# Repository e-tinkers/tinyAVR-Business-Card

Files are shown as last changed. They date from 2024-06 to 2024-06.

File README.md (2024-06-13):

## tinyAVR Business Card

This is my entry for Hackaday 2024 Business Card Challenge Contest.

A business card with contact info and QR Code, plus a charlieplexed realtime clock powered by a CR2016 coin cell with extremely low battery power consumption, it is also a complete ATtiny3227 development board with all the pins break-out.

"PCB name card side"
"PCB component side"

### Feature Highlights

- Business with contact information and QRCode for website
- Credit card size of 85.5x54mm
- 3.2mm thickness including 1mm PCB
- It is a clock/watch with 12 Charlieplexing LEDs
- It is also a ATtiny3227 development board with all the pins (22-GPIO pins) break-out.
- Programmable with [megaTinyCore](https://github.com/SpenceKonde/megaTinyCore/tree/master/megaavr) as an Arduino or with bare metal with just VSCode and avrdude. 
- Powered by a CR2016 coin cell battery (98mAh)
- Designed for low-power, with design target of 1-2uA during sleep, and 2.5mA when time is showed.
- More than 3 years battery life based on viewing the time 24 times a day.
- Less than \$8.00 BOM (based on sourcing from DigiKey).

Further description can be found at https://hackaday.io/project/196294-business-card-clock-attiny3227-dev-board.

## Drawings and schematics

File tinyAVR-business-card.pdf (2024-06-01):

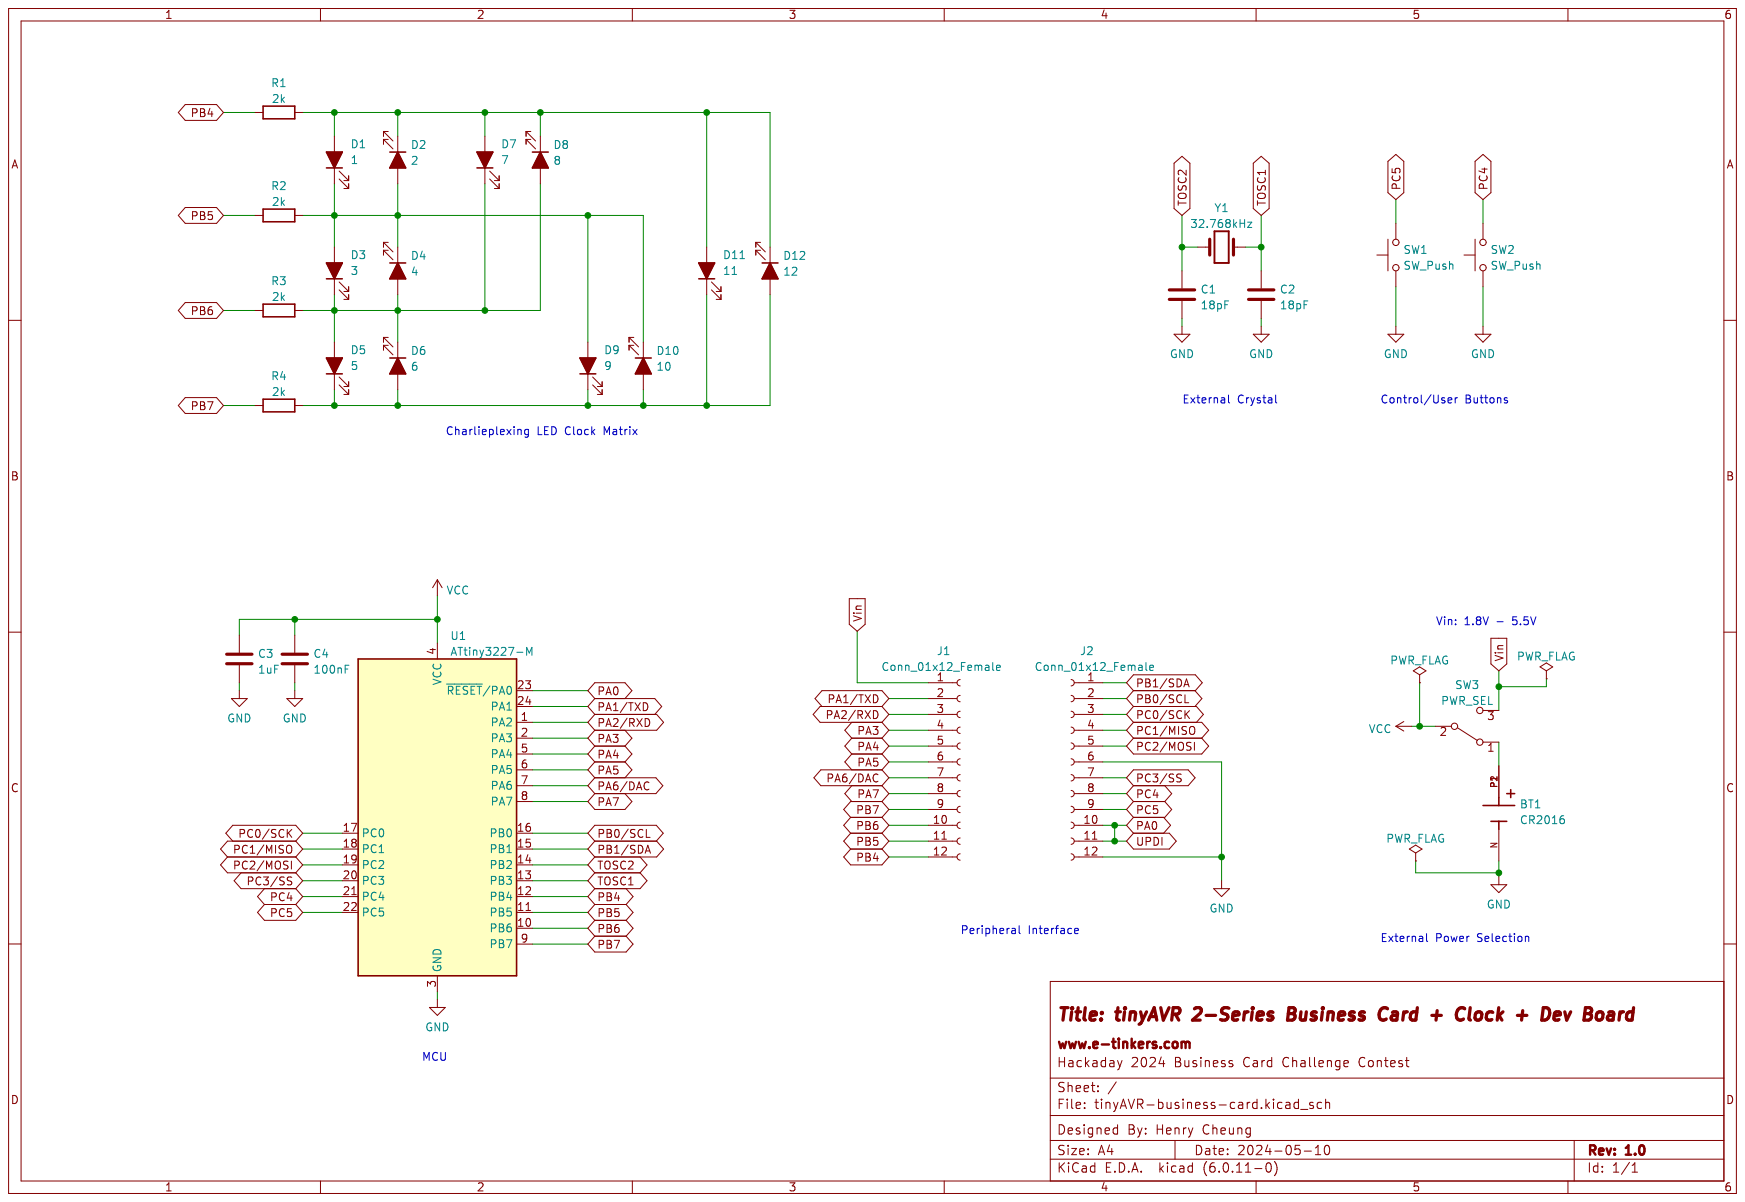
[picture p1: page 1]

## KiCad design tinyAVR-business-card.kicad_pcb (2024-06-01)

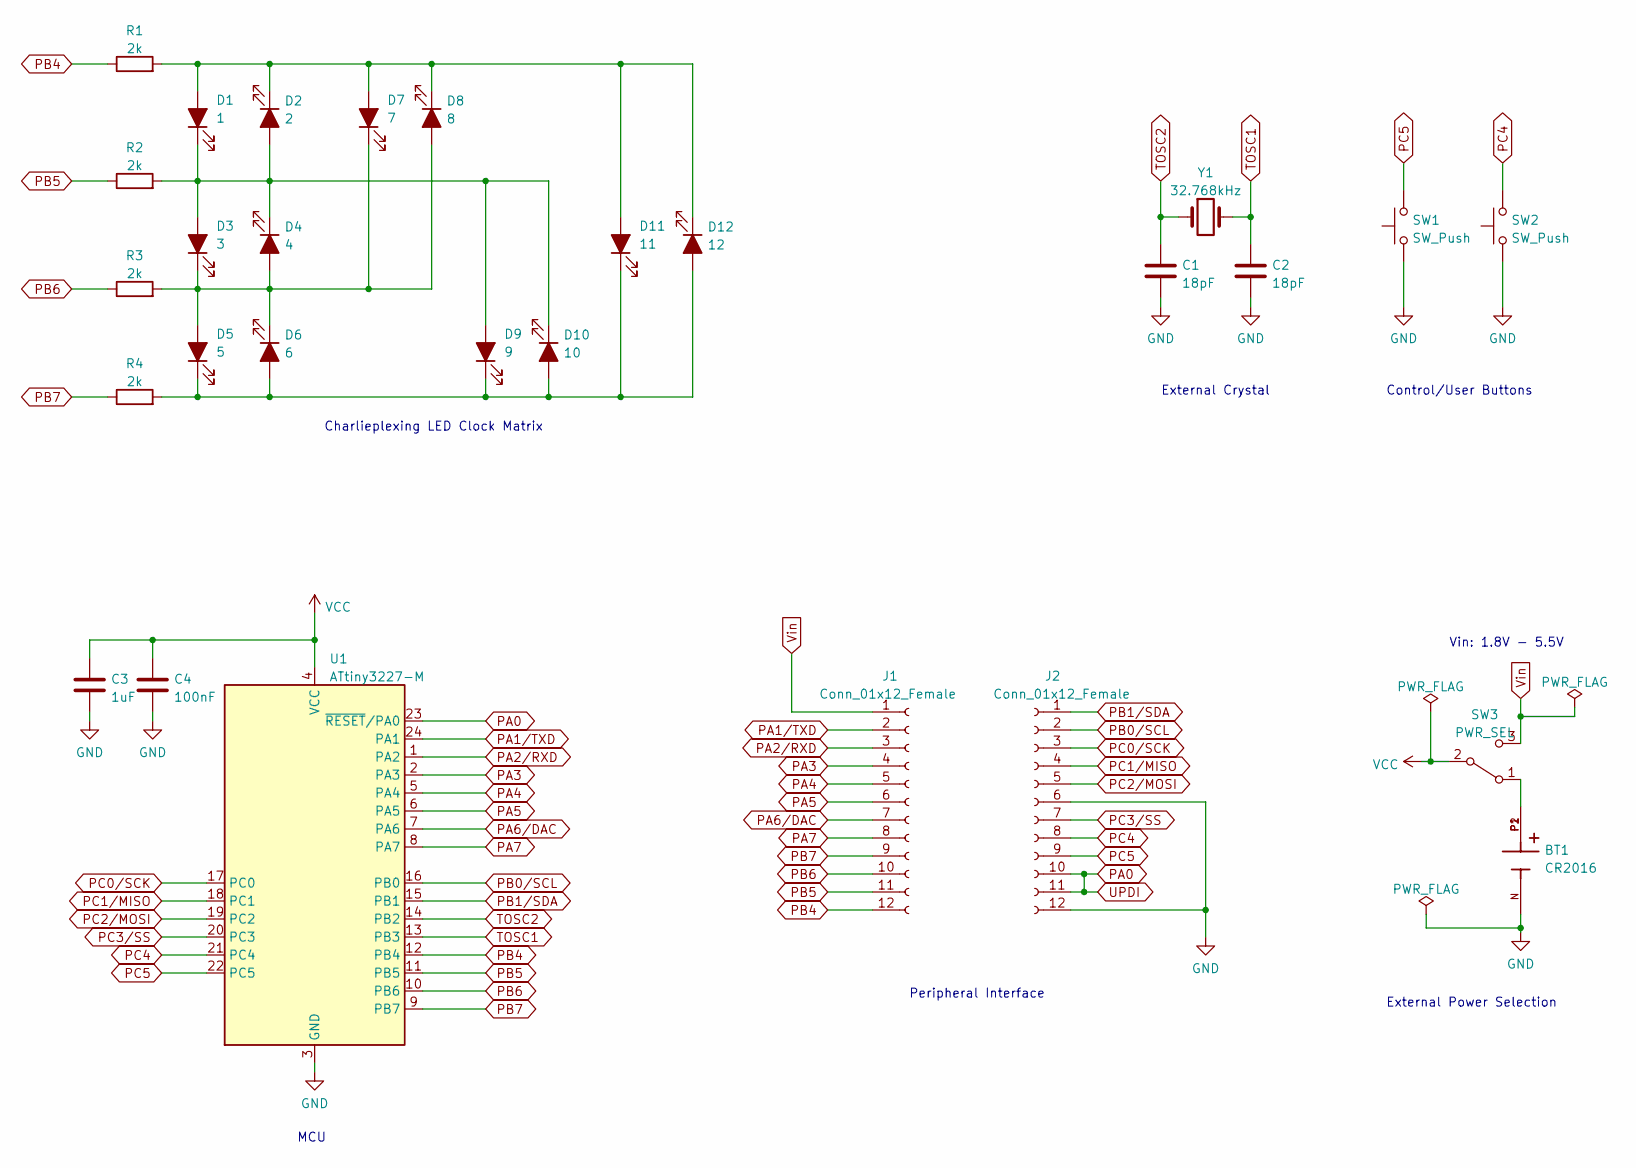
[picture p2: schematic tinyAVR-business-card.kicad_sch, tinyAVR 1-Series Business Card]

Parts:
BT1: CR2016; BatteryHolder_CR2016_SMD
C1, C2: 18pF; C_0603_1608Metric
C3: 1uF; C_0603_1608Metric
C4: 100nF; C_0603_1608Metric
D1: 1; LED_0603_1608Metric
D2: 2; LED_0603_1608Metric
D3: 3; LED_0603_1608Metric
D4: 4; LED_0603_1608Metric
D5: 5; LED_0603_1608Metric
D6: 6; LED_0603_1608Metric
D7: 7; LED_0603_1608Metric
D8: 8; LED_0603_1608Metric
D9: 9; LED_0603_1608Metric
D10: 10; LED_0603_1608Metric
D11: 11; LED_0603_1608Metric
D12: 12; LED_0603_1608Metric
J1, J2: Conn_01x12_Female; HDR-SMD_12P-P2.54-H-F-L11.5
R1, R2, R3, R4: 2k; R_0603_1608Metric
SW1, SW2: SW_Push; XKB_Connection_TS-1185-B-A-B-A
SW3: PWR_SEL; SW_SPDT_XKB_SK-3390A-L1
U1: ATtiny3227-M; QFN-24-1EP_4x4mm_P0.5mm_EP2.6x2.6mm
Y1: 32.768kHz; Crystal_SMD_3215-2Pin_3.2x1.5mm

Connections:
GND: BT1.N, C1.2, C2.2, C3.2, C4.2, J2.6, J2.12, SW1.1, SW2.1, U1.3 (GND), U1.25 (GND)
unnamed: BT1.P1, BT1.P2, SW3.1 (A)
unnamed: D1.1 (K), D2.2 (A), D3.2 (A), D4.1 (K), D9.2 (A), D10.1 (K), R2.2
unnamed: D1.2 (A), D2.1 (K), D7.2 (A), D8.1 (K), D11.2 (A), D12.1 (K), R1.2
unnamed: D3.1 (K), D4.2 (A), D5.2 (A), D6.1 (K), D7.1 (K), D8.2 (A), R3.2
unnamed: D5.1 (K), D6.2 (A), D9.1 (K), D10.2 (A), D11.1 (K), D12.2 (A), R4.2
PA0: J2.10, J2.11, U1.23 (~RESET/PA0)
PA1/TXD: J1.2, U1.24 (PA1)
PA2/RXD: J1.3, U1.1 (PA2)
PA3: J1.4, U1.2 (PA3)
PA4: J1.5, U1.5 (PA4)
PA5: J1.6, U1.6 (PA5)
PA6/DAC: J1.7, U1.7 (PA6)
PA7: J1.8, U1.8 (PA7)
PB0/SCL: J2.2, U1.16 (PB0)
PB1/SDA: J2.1, U1.15 (PB1)
PB4: J1.12, R1.1, U1.12 (PB4)
PB5: J1.11, R2.1, U1.11 (PB5)
PB6: J1.10, R3.1, U1.10 (PB6)
PB7: J1.9, R4.1, U1.9 (PB7)
PC0/SCK: J2.3, U1.17 (PC0)
PC1/MISO: J2.4, U1.18 (PC1)
PC2/MOSI: J2.5, U1.19 (PC2)
PC3/SS: J2.7, U1.20 (PC3)
PC4: J2.8, SW2.2, U1.21 (PC4)
PC5: J2.9, SW1.2, U1.22 (PC5)
TOSC1: C2.1, U1.13 (PB3), Y1.2
TOSC2: C1.1, U1.14 (PB2), Y1.1
VCC: C3.1, C4.1, SW3.2 (B), U1.4 (VCC)
Vin: J1.1, SW3.3 (C)

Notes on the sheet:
External Crystal
MCU
Control/User Buttons
Peripheral Interface
Vin: 1.8V - 5.5V
Charlieplexing LED Clock Matrix
External Power Selection

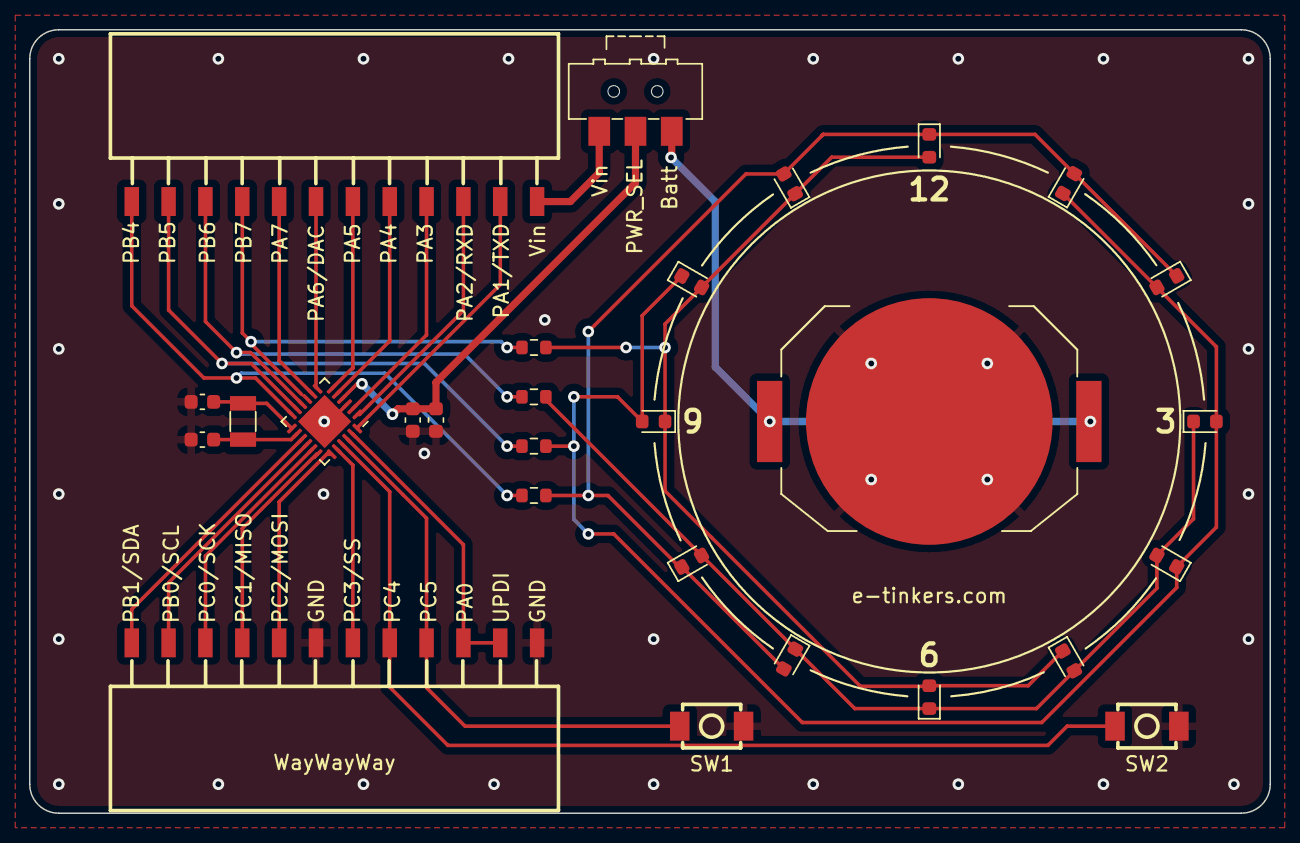
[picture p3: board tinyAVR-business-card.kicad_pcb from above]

Board: 2 copper layers, 85.5 x 54.0 mm, 28 parts (0 on the bottom side), 30 nets.

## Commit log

2024-06-01 correct type on tinyAVR 1-series
    [tinyAVR-business-card.kicad_sch]
2024-06-13 replace PCB rendering with actual PCB images
2024-06-13 remove gerber files
    [tinyAVR-business-card-B_Cu.gbr, tinyAVR-business-card-B_Mask.gbr, tinyAVR-business-card-B_Paste.gbr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]
